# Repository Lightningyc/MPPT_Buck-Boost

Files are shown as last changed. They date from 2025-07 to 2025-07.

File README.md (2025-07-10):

&nbsp;&nbsp;

[English](./README.md)/中文

***
初赛演示视频：[2025年嵌入式设计大赛ST赛道-基于 STM32G4 平台的数控 MPPT 四开关 buckboost 变换器](https://www.bilibili.com/video/BV1HrGgzEE6s/)

# 作品实物图

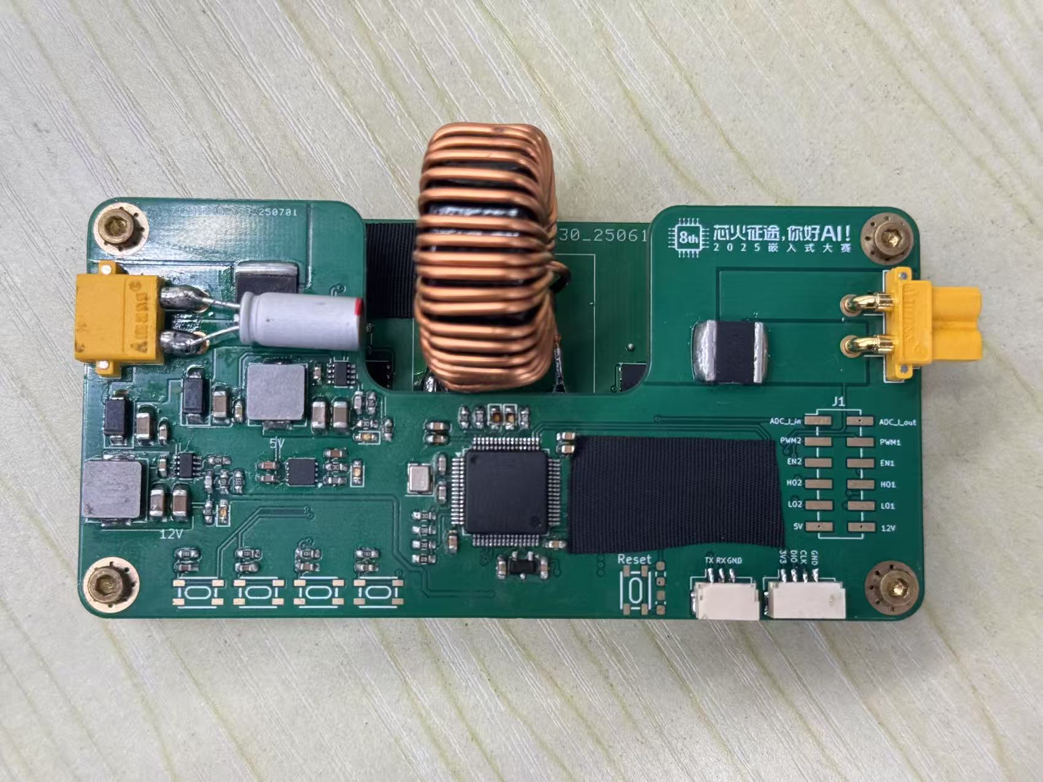
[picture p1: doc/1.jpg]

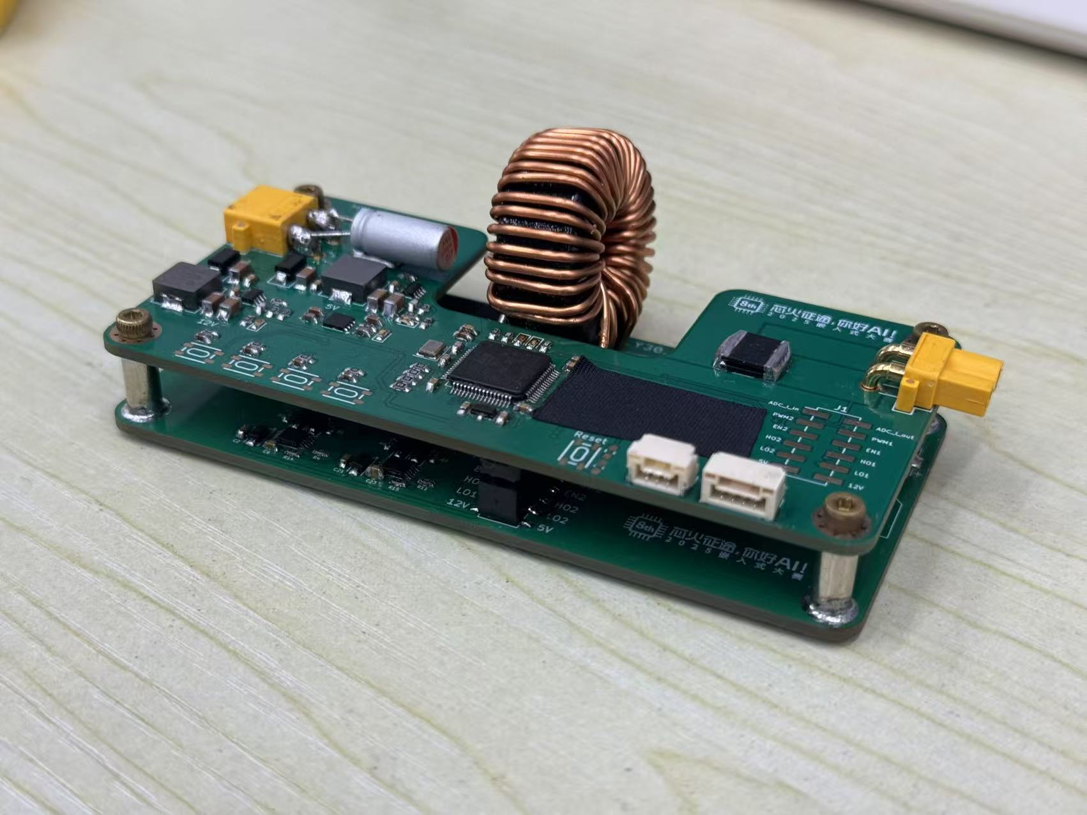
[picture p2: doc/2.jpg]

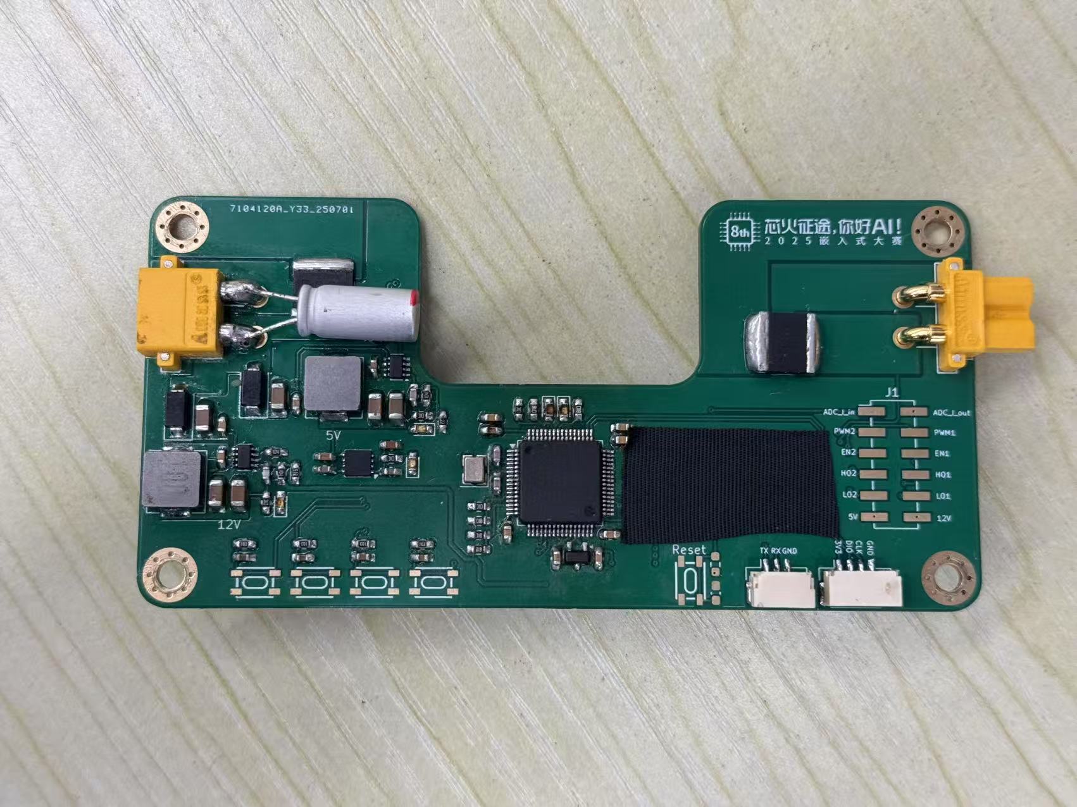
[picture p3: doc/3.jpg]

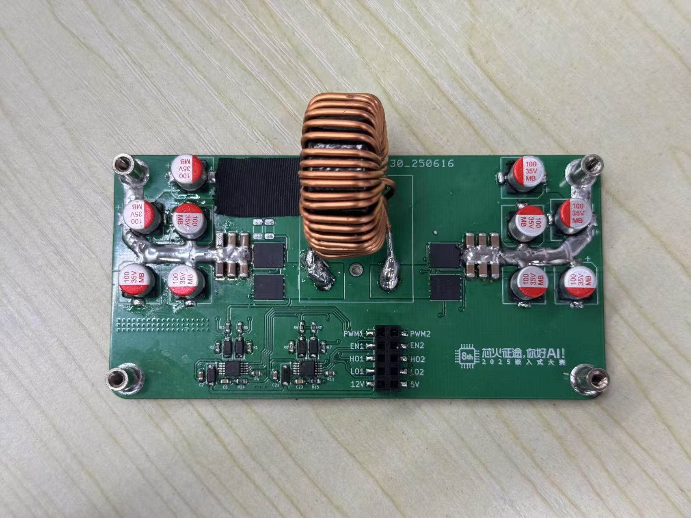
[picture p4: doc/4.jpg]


# 1. 作品简介

## 1.1 关键性能指标
**输出电压：**
最高输出电压：10.74V

最低输出电压：15.20V

**稳态平均功率：**

12.39W

**稳态功率波动：**

0.02%

**最大功率点跟踪效率：**

94.8%
## 1.2 主要创新点

1. 双模式 MPPT 算法：结合 CV 法快速定位与 P&O 法动态跟踪，提高追
踪精度，加强了抗光照突变干扰能力。

2. 太阳能控制器硬件部分采用双板结构：控制板含 MCU 最小系统、采
样电路及调试接口；功率板集成主变换电路、驱动及滤波电路。全部设计基
于 KiCad 完成，兼顾调试便利与高低压隔离需求。

3. 使用 PSIM 仿真：充分利用 PSIM 仿真软件进行算法验证和参数优化，
实现了仿真与硬件开发的双线并行，提高了工作效率，还能提前发现潜在问
题，为后续硬件调试奠定了坚实基础。

# 2. 系统介绍

下图所示的太阳能控制器系统包含以下核心模块：DC-DC 电能变换电路、电压电流采样电路、输入输出滤波电路以及辅助电源电路。系统工作原理如下：

能量输入与处理：光伏电池板转换的太阳能电能，经输入滤波电路预处理后，输入至 DC-DC 变换电路。

状态监测：STM32G74 微控制器周期性采集经采样电路获取的输入/输出电压电流数据。

核心控制：微控制器对采集数据进行线性拟合，并运行内部 MPPT 算法，计算出控制指令。

功率调节：控制指令转化为PWM信号输出至栅极驱动器，驱动 DC-DC 变换电路的功率开关器件，从而动态调整其工作状态（如占空比），实现对输入或输出电参数的精准控制。

通信交互： 控制器通过 UART 接口与上位机软件 Vofa+ 通信，支持参数远程设定及实时运行数据（电压/电流）反馈。

安全保障与供电：

输入端设有防电流倒灌电路，防止能量逆向流动。

辅助电源电路集成提供 12V、5V 和 3.3V 的板级电源，为控制器内部所有模块稳定供电。

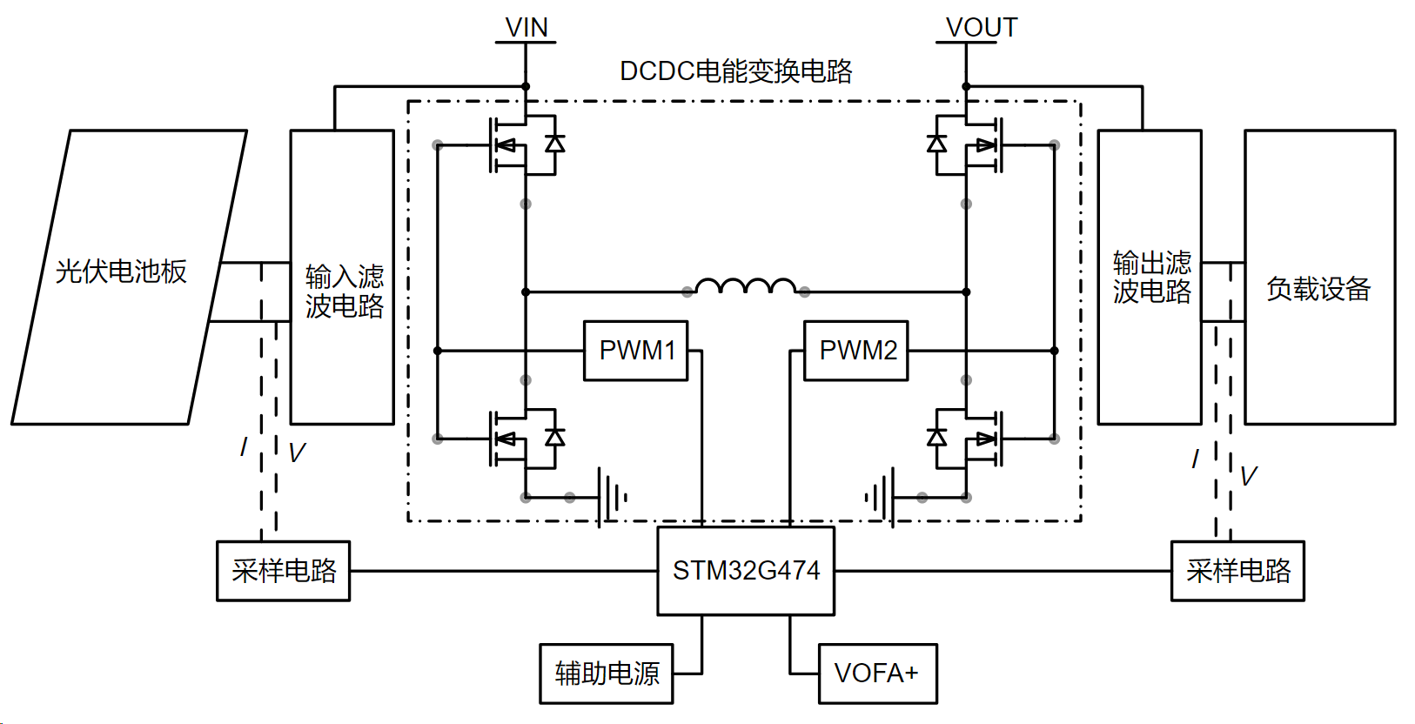
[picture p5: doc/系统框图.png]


考虑到调试方便性以及高低压域分割问题，本文中的太阳能电池板控制器的硬件系统主要由控制部分与功率部分两块 PCB 板组合而成，其如图 2 所示，控制部分主要包括主控 MCU 最小系统、辅助电源、采样电路、调试接口和指示灯；功率部分主要包括电能变换主电路，输入输出滤波电路和栅极驱动电路。本作品的硬件全流程设计均基于 Kicad 软件。

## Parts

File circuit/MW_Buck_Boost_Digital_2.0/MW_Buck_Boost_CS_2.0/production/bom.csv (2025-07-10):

Designator | Footprint | Quantity | Value | LCSC Part #
C1, C10, C11, C12, C13, C14, C15, C2, C22, C23, C24, C26, C3, C6, C7, C8, C9 | 0603 | 17 | 100n
C19, C20 | 1206 | 2 | 106 1206
C21, C25 | 0603 | 2 | 4.7u
C27, C28 | 0603 | 2 | 103
C29, C30 | 0603 | 2 | 101
C31, C32, C33, C34 | 1206 | 4 | 22uf 0603
C4, C5 | 0603 | 2 | 10p
D10, D8, D9 | 0603 | 3 | LED
D3 | 0603 | 1 | blue
D5 | 0603 | 1 | green
D6, D7 | D_SMA | 2 | B140-E3
H1, H2, H3, H4 | MountingHole_3.2mm_M3_Pad_Via | 4 | MountingHole_Pad
J2 | XT30PW-M | 1 | Conn_01x02
J3 | XT30PW-F | 1 | Conn_01x02
J4 | PinHeader_2x06_P2.54mm_Vertical_SMD | 1 | Conn_02x06_Odd_Even
J5 | JST_GH_SM04B-GHS-TB_1x04-1MP_P1.25mm_Horizontal | 1 | Conn_01x04
J6 | JST_GH_SM03B-GHS-TB_1x03-1MP_P1.25mm_Horizontal | 1 | Conn_01x03
J7 | PinSocket_1x04_P2.54mm_Vertical | 1 | Conn_01x04
J8 | PinHeader_2x05_P2.54mm_Vertical_SMD | 1 | Conn_02x05_Odd_Even
L1 | L_Abracon_ASPI-0630LR | 1 | 10uH
L2 | L_Abracon_ASPI-0630LR | 1 | 15uH
R10, R11, R3, R4, R8, R9 | 0603 | 6 | 10k
R12, R13 | 0603 | 2 | 6k
R14, R15, R18, R23, R24, R5, R7 | 0603 | 7 | 1k
R16, R17, R19, R21 | 0603 | 4 | 100k
R2 | Resistance | 1 | 8m
R20 | 0603 | 1 | 5.26k
R22 | 0603 | 1 | 11.4k
SW1, SW2, SW3, SW4, SW5 | SW-SMD_4P-L4.2-W3.3-P2.15-LS5.1 | 5 | SW_Push
U1 | SOT-23 | 1 | REF3030
U2 | LQFP-64_10x10mm_P0.5mm | 1 | STM32G474RCTx
U3 | SOT-23-5 | 1 | INA180A3
U6 | DFN-8-1EP_3x3mm_P0.65mm_EP1.55x2.4mm | 1 | AP7361C
U7, U8 | SOT-23-8 | 2 | SY8303
Y1 | Crystal_SMD_3225-4Pin_3.2x2.5mm | 1 | 25M

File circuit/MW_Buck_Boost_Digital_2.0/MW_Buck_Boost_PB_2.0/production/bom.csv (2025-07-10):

Designator | Footprint | Quantity | Value | LCSC Part #
C1, C13, C27, C28, C29, C3, C32, C33, C34, C4, C7, C8, C9 | 1206 | 13 | 22uf
C15, C16, C17, C18, C20, C35, C36, C38, C39, C40 | CP_Elec_8x10 | 10 | 100uf
C2, C21 | 0603 | 2 | 2.2uf
C23, C6 | 0603 | 2 | 10uf
D1, D2, D3, D6, D7, D8 | D_SOD-123 | 6 | B140-E3
H1, H2, H3, H4 | MountingHole_3.2mm_M3_Pad_Via | 4 | MountingHole_Pad
J2 | PinHeader_2x05_P2.54mm_Vertical_SMD | 1 | Conn_02x05_Odd_Even
L1 | PQ2918 | 1 | 47uH
Q1, Q2, Q3, Q4 | TDSON-8-1 | 4 | CSD18540Q5B
R1, R2, R7, R8 | 0603 | 4 | 4.7
R11, R3, R4, R5, R6, R9 | 0603 | 6 | 10k
R14, R15 | 0603 | 2 | 4.7R
R16 | 1206 | 1 | 4.7
U1, U2 | SOP50P490X110-10N | 2 | LM5106MM/NOPB

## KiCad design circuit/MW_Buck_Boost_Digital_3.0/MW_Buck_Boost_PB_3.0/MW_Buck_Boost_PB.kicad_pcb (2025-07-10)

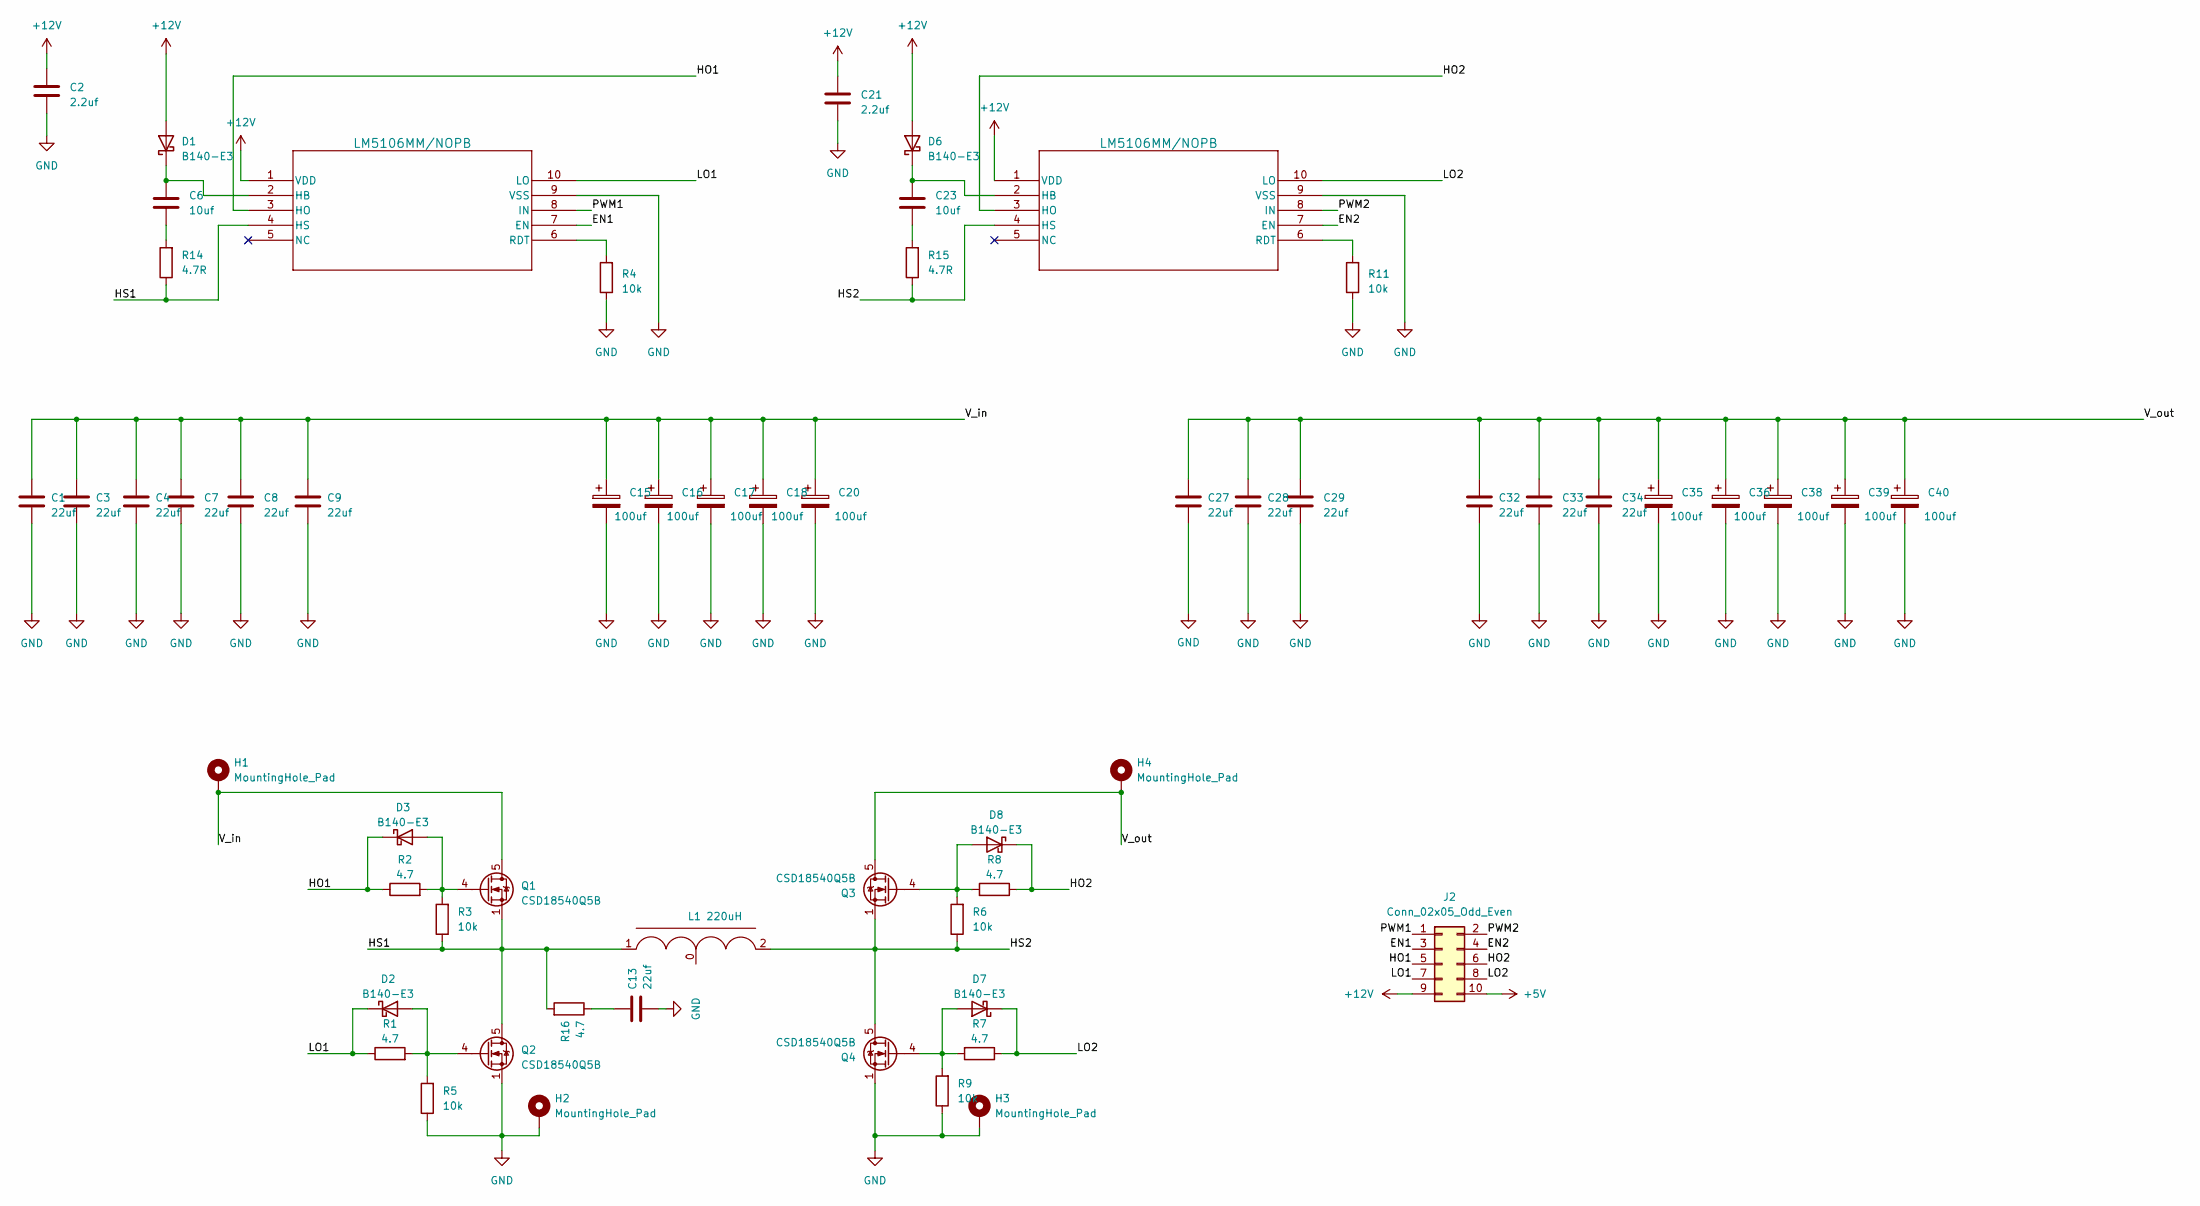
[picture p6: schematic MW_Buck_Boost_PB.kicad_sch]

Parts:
C1, C3, C4, C7, C8, C9, C13, C27, C28, C29, C32, C33, C34: 22uf; C_1206_3216Metric
C2, C21: 2.2uf; C_0603_1608Metric
C6, C23: 10uf; C_0603_1608Metric
C15, C16, C17, C18, C20, C35, C36, C38, C39, C40: 100uf; CP_Elec_8x10
D1, D2, D3, D6, D7, D8: B140-E3; D_SOD-123
H1, H2, H3, H4: MountingHole_Pad; MountingHole_3.2mm_M3_Pad_Via
J2: Conn_02x05_Odd_Even; PinHeader_2x05_P2.54mm_Vertical_SMD
L1: 220uH; L_Wurth_WE-HCFT-2012_LeadDiameter1.2mm
Q1, Q2, Q3, Q4: CSD18540Q5B; TDSON-8-1
R1, R2, R7, R8: 4.7; R_0603_1608Metric
R3, R4, R5, R6, R9, R11: 10k; R_0603_1608Metric
R14, R15: 4.7R; R_0603_1608Metric
R16: 4.7; R_1206_3216Metric
U1, U2: LM5106MM/NOPB; SOP50P490X110-10N

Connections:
+5V: J2.10
+12V: C2.1, C21.1, D1.2 (A), D6.2 (A), J2.9, U1.1 (VDD), U2.1 (VDD)
/EN1: J2.3, U1.7 (EN)
/EN2: J2.4, U2.7 (EN)
/HO1: D3.1 (K), J2.5, R2.1, U1.3 (HO)
/HO2: D8.1 (K), J2.6, R8.1, U2.3 (HO)
/HS1: L1.1, Q1.1 (S), Q1.2 (S), Q1.3 (S), Q2.5 (D), R3.1, R14.1, R16.2, U1.4 (HS)
/HS2: L1.2, Q3.1 (S), Q3.2 (S), Q3.3 (S), Q4.5 (D), R6.1, R15.1, U2.4 (HS)
/LO1: D2.1 (K), J2.7, R1.1, U1.10 (LO)
/LO2: D7.1 (K), J2.8, R7.1, U2.10 (LO)
/PWM1: J2.1, U1.8 (IN)
/PWM2: J2.2, U2.8 (IN)
/V_in: C1.1, C3.1, C4.1, C7.1, C8.1, C9.1, C15.1, C16.1, C17.1, C18.1, C20.1, H1.1, Q1.5 (D)
/V_out: C27.1, C28.1, C29.1, C32.1, C33.1, C34.1, C35.1, C36.1, C38.1, C39.1, C40.1, H4.1, Q3.5 (D)
GND: C1.2, C2.2, C3.2, C4.2, C7.2, C8.2, C9.2, C13.2, C15.2, C16.2, C17.2, C18.2, C20.2, C21.2, C27.2, C28.2, C29.2, C32.2, C33.2, C34.2, C35.2, C36.2, C38.2, C39.2, C40.2, H2.1, H3.1, Q2.1 (S), Q2.2 (S), Q2.3 (S), Q4.1 (S), Q4.2 (S), Q4.3 (S), R4.1, R5.1, R9.1, R11.1, U1.9 (VSS), U2.9 (VSS)
unnamed: C6.2, R14.2
unnamed: C13.1, R16.1
unnamed: C23.2, R15.2
unnamed: C6.1, D1.1 (K), U1.2 (HB)
unnamed: D2.2 (A), Q2.4 (G), R1.2, R5.2
unnamed: D3.2 (A), Q1.4 (G), R2.2, R3.2
unnamed: C23.1, D6.1 (K), U2.2 (HB)
unnamed: D7.2 (A), Q4.4 (G), R7.2, R9.2
unnamed: D8.2 (A), Q3.4 (G), R6.2, R8.2
unnamed: R4.2, U1.6 (RDT)
unnamed: R11.2, U2.6 (RDT)

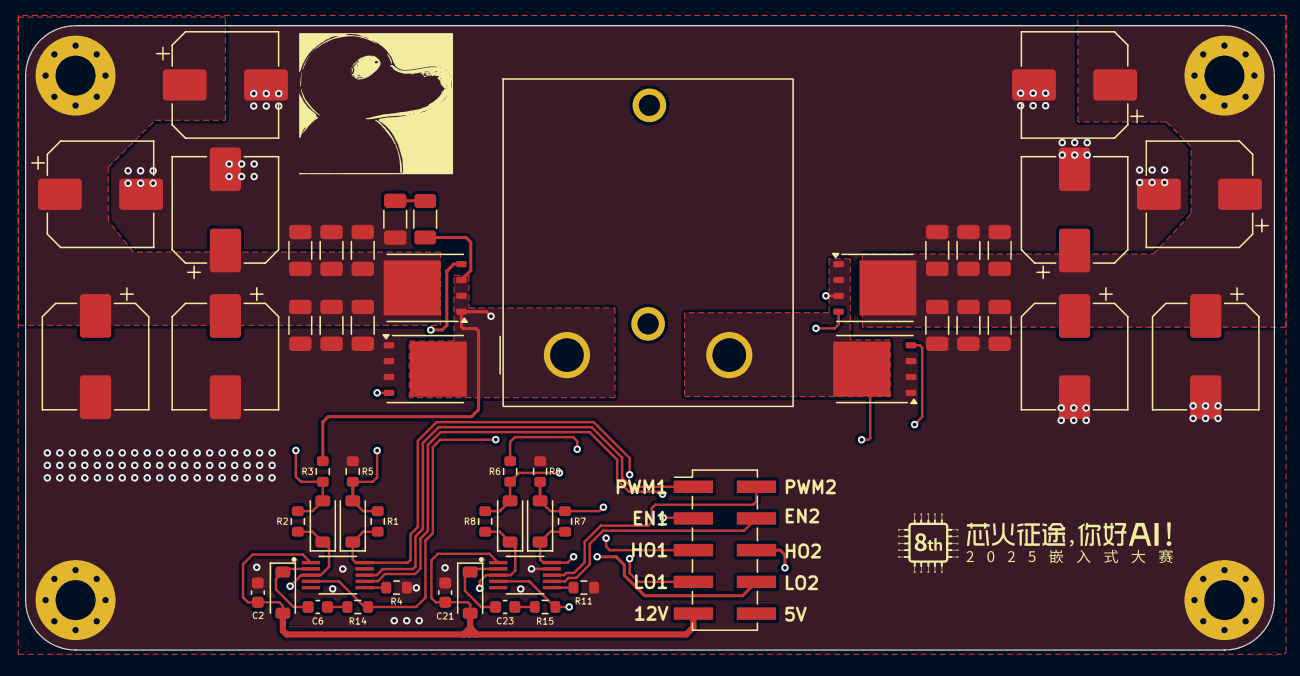
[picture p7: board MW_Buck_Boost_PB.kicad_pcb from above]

Board: 4 copper layers, 100.0 x 50.0 mm, 58 parts (0 on the bottom side), 25 nets.

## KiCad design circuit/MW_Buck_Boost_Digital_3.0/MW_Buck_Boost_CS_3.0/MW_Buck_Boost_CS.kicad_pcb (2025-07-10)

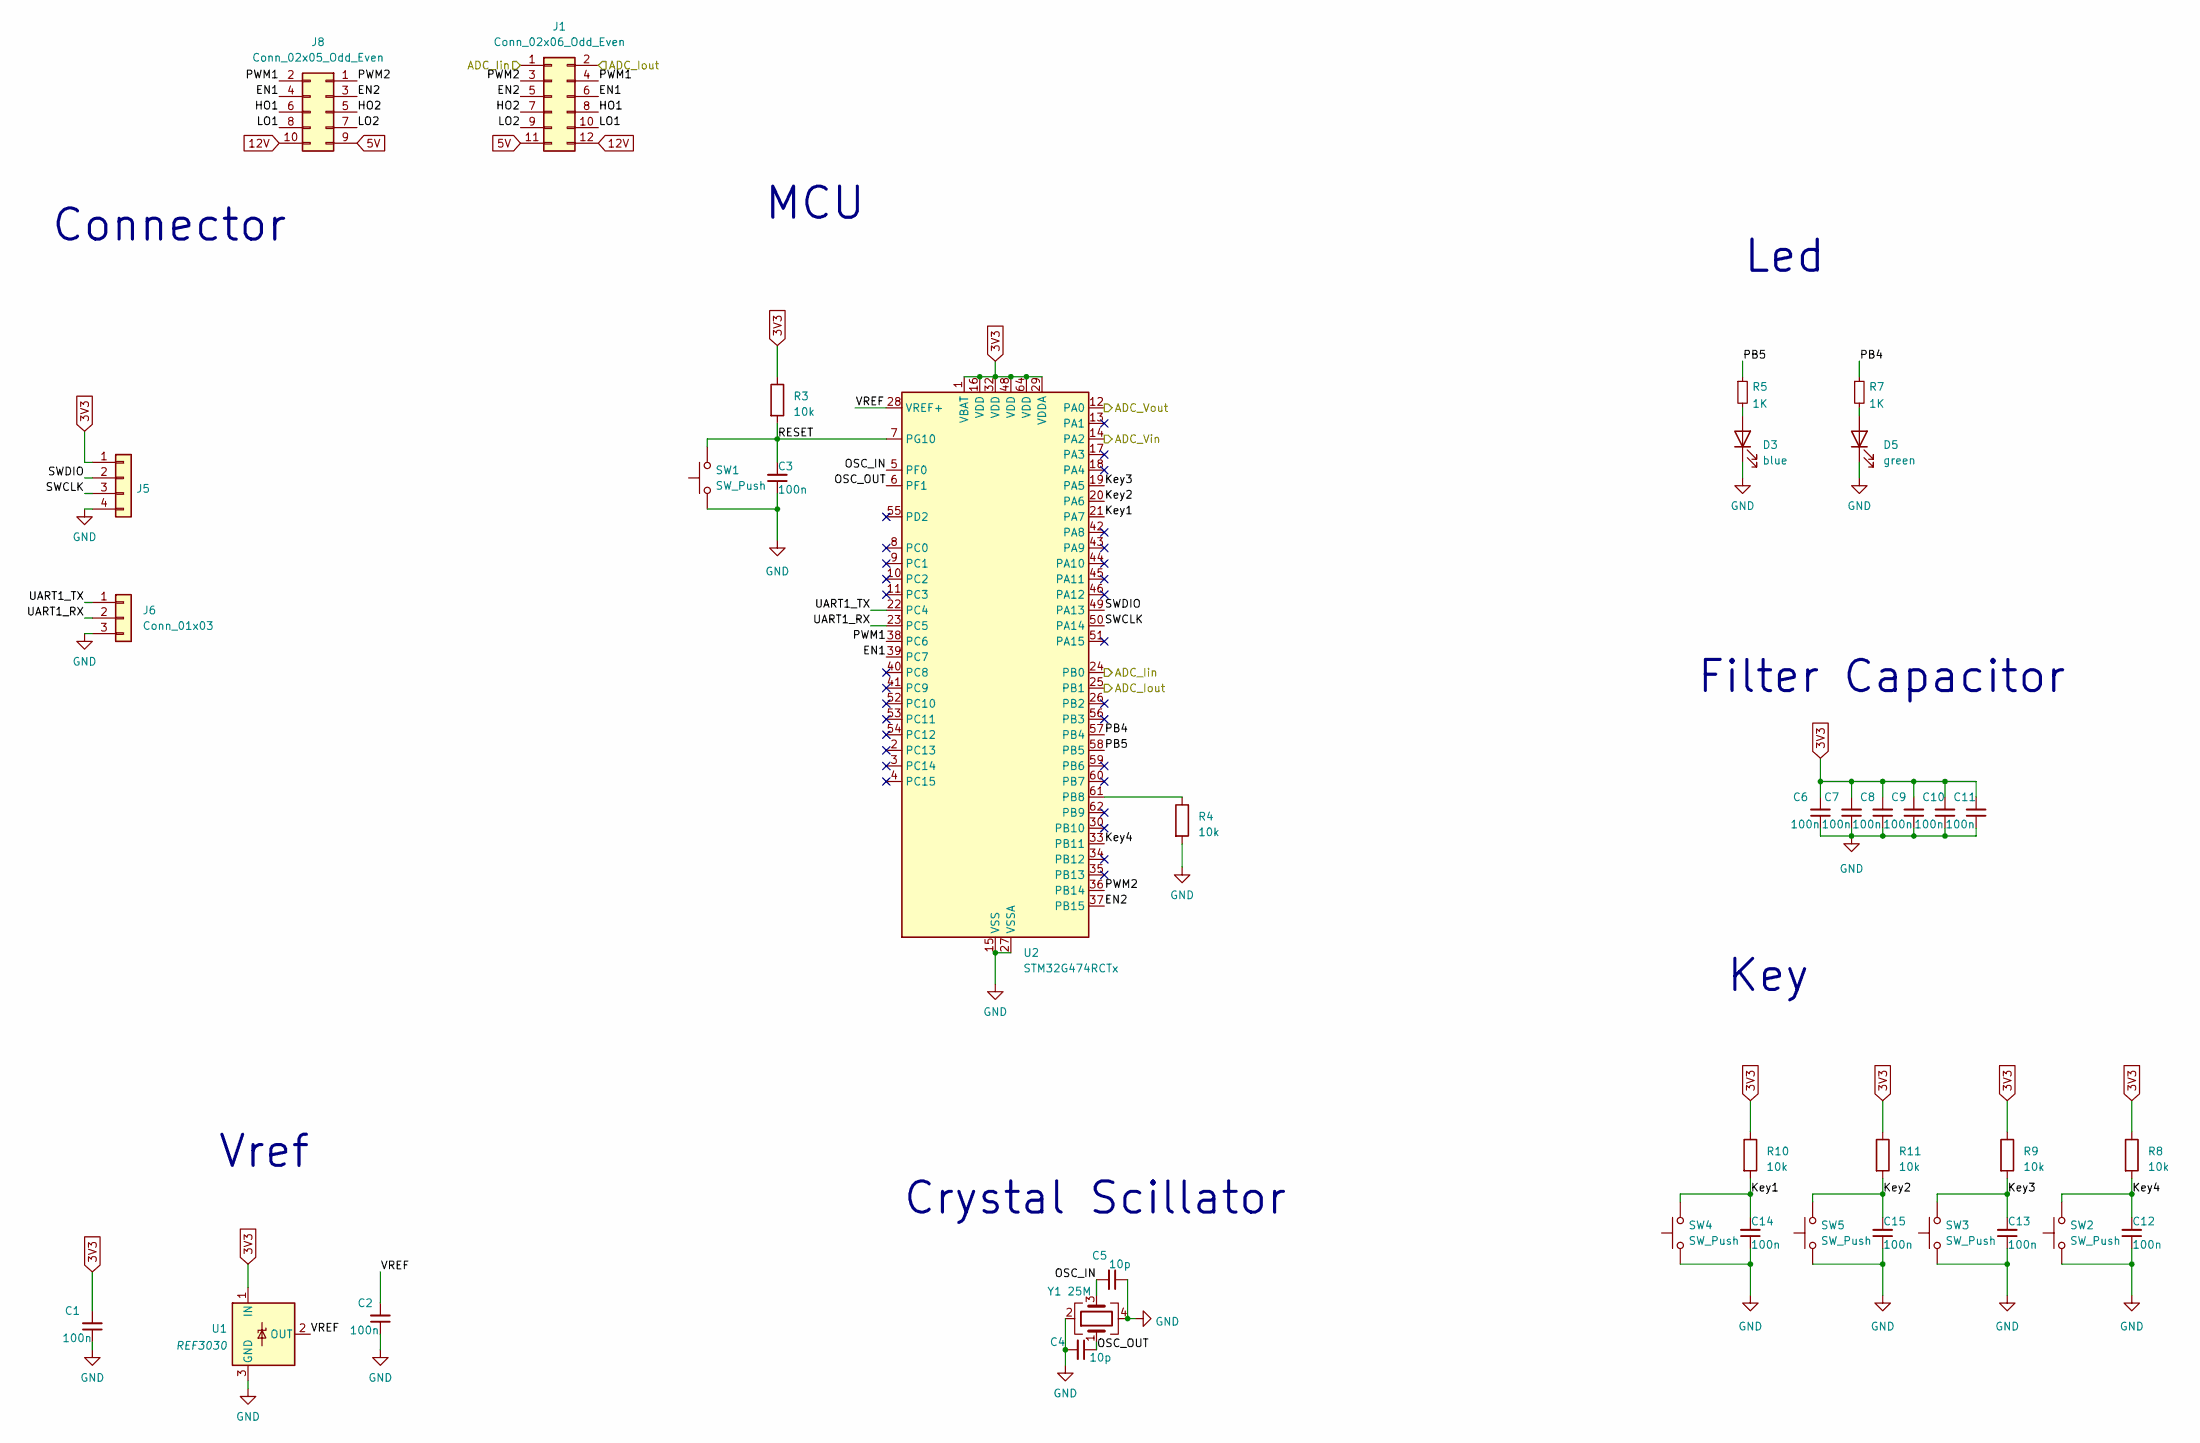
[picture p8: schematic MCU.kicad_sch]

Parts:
C1, C2, C3, C6, C7, C8, C9, C10, C11, C12, C13, C14, C15: 100n; C_0603_1608Metric_Pad1.08x0.95mm_HandSolder
C4, C5: 10p; C_0603_1608Metric_Pad1.08x0.95mm_HandSolder
D3: blue; LED_0603_1608Metric_Pad1.05x0.95mm_HandSolder
D5: green; LED_0603_1608Metric_Pad1.05x0.95mm_HandSolder
J1: Conn_02x06_Odd_Even; PinHeader_2x06_P2.54mm_Vertical_SMD
J5: Conn_01x04; JST_GH_SM04B-GHS-TB_1x04-1MP_P1.25mm_Horizontal
J6: Conn_01x03; JST_GH_SM03B-GHS-TB_1x03-1MP_P1.25mm_Horizontal
J8: Conn_02x05_Odd_Even; PinHeader_2x05_P2.54mm_Vertical_SMD
R3, R4, R8, R9, R10, R11: 10k; R_0603_1608Metric_Pad0.98x0.95mm_HandSolder
R5, R7: 1K; R_0603_1608Metric_Pad0.98x0.95mm_HandSolder
SW1, SW2, SW3, SW4, SW5: SW_Push; SW-SMD_4P-L4.2-W3.3-P2.15-LS5.1
U1: REF3030; SOT-23
U2: STM32G474RCTx; LQFP-64_10x10mm_P0.5mm
Y1: 25M; Crystal_SMD_3225-4Pin_3.2x2.5mm

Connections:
3V3: C1.2, C6.2, C7.2, C8.2, C9.2, C10.2, C11.2, J5.1, R3.1, R8.1, R9.1, R10.1, R11.1, U1.1 (IN), U2.1 (VBAT), U2.16 (VDD), U2.29 (VDDA), U2.32 (VDD), U2.48 (VDD), U2.64 (VDD); also elsewhere on the board
5V: J1.11, J8.9; also elsewhere on the board
12V: J1.12, J8.10; also elsewhere on the board
/MCU/ADC_Iin: J1.1, U2.24 (PB0); also elsewhere on the board
/MCU/ADC_Iout: J1.2, U2.25 (PB1); also elsewhere on the board
/MCU/ADC_Vin: U2.14 (PA2); also elsewhere on the board
/MCU/ADC_Vout: U2.12 (PA0); also elsewhere on the board
/MCU/EN1: J1.6, J8.4, U2.39 (PC7)
/MCU/EN2: J1.5, J8.3, U2.37 (PB15)
/MCU/HO1: J1.8, J8.6
/MCU/HO2: J1.7, J8.5
/MCU/Key1: C14.2, R10.2, SW4.2, U2.21 (PA7)
/MCU/Key2: C15.2, R11.2, SW5.2, U2.20 (PA6)
/MCU/Key3: C13.2, R9.2, SW3.2, U2.19 (PA5)
/MCU/Key4: C12.2, R8.2, SW2.2, U2.33 (PB11)
/MCU/LO1: J1.10, J8.8
/MCU/LO2: J1.9, J8.7
/MCU/OSC_IN: C5.2, U2.5 (PF0), Y1.3
/MCU/OSC_OUT: C4.1, U2.6 (PF1), Y1.1
/MCU/PB4: R7.1, U2.57 (PB4)
/MCU/PB5: R5.1, U2.58 (PB5)
/MCU/PWM1: J1.4, J8.2, U2.38 (PC6)
/MCU/PWM2: J1.3, J8.1, U2.36 (PB14)
/MCU/RESET: C3.2, R3.2, SW1.2, U2.7 (PG10)
/MCU/SWCLK: J5.3, U2.50 (PA14)
/MCU/SWDIO: J5.2, U2.49 (PA13)
/MCU/UART1_RX: J6.2, U2.23 (PC5)
/MCU/UART1_TX: J6.1, U2.22 (PC4)
/MCU/VREF: C2.2, U1.2 (OUT), U2.28 (VREF+)
GND: C1.1, C2.1, C3.1, C4.2, C5.1, C6.1, C7.1, C8.1, C9.1, C10.1, C11.1, C12.1, C13.1, C14.1, C15.1, D3.1 (K), D5.1 (K), J5.4, J6.3, R4.2, SW1.1, SW2.1, SW3.1, SW4.1, SW5.1, U1.3 (GND), U2.15 (VSS), U2.27 (VSSA), U2.31 (VSS), U2.47 (VSS), U2.63 (VSS), Y1.2, Y1.4; also elsewhere on the board
unnamed: D3.2 (A), R5.2
unnamed: D5.2 (A), R7.2
unnamed: R4.1, U2.61 (PB8)

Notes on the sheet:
Connector
Led
Vref
Crystal Scillator
MCU
Filter Capacitor
Key

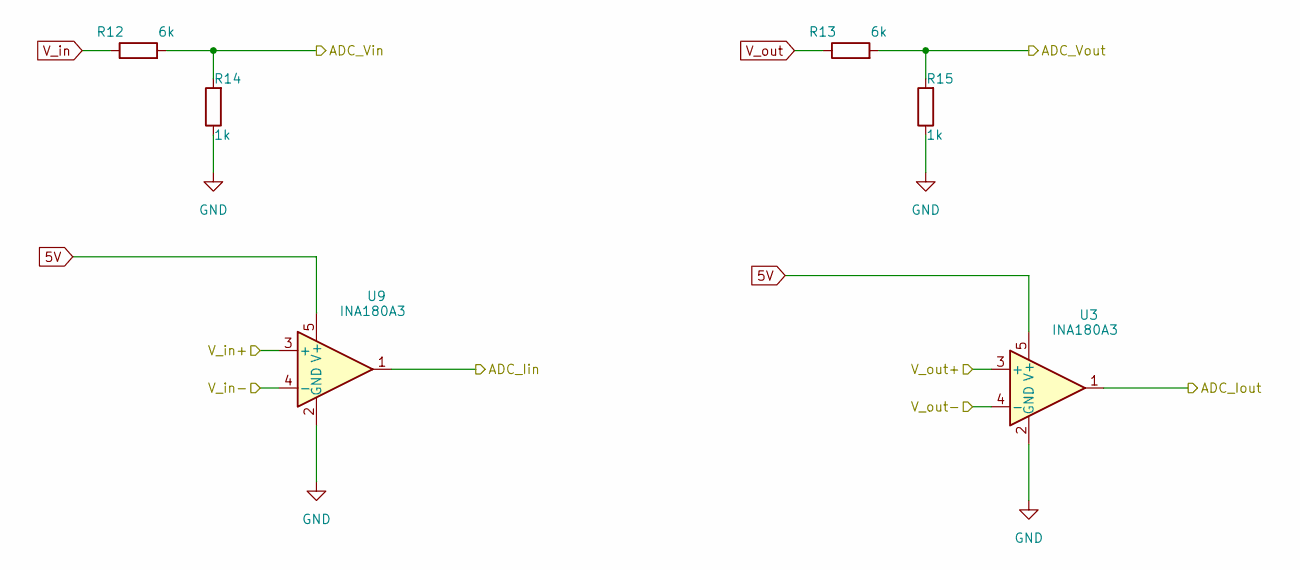
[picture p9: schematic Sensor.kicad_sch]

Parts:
R12, R13: 6k; R_0603_1608Metric_Pad0.98x0.95mm_HandSolder
R14, R15: 1k; R_0603_1608Metric_Pad0.98x0.95mm_HandSolder
U3, U9: INA180A3; SOT-23-5

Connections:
5V: U3.5 (V+), U9.5 (V+); also elsewhere on the board
/MCU/ADC_Iin: U9.1; also elsewhere on the board
/MCU/ADC_Iout: U3.1; also elsewhere on the board
/MCU/ADC_Vin: R12.2, R14.2; also elsewhere on the board
/MCU/ADC_Vout: R13.2, R15.2; also elsewhere on the board
/MainCircuit/V_in-: U9.4 (-); also elsewhere on the board
/MainCircuit/V_out+: U3.3 (+); also elsewhere on the board
GND: R14.1, R15.1, U3.2 (GND), U9.2 (GND); also elsewhere on the board
V_in: R12.1, U9.3 (+); also elsewhere on the board
V_out: R13.1, U3.4 (-); also elsewhere on the board

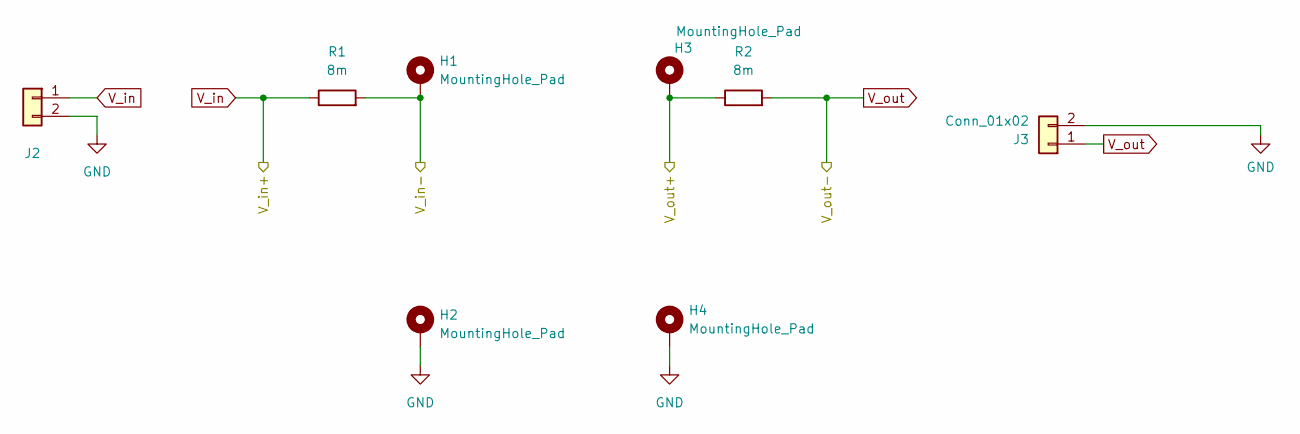
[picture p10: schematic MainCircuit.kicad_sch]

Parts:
H1, H2, H3, H4: MountingHole_Pad; MountingHole_3.2mm_M3_Pad_Via
J2: Conn_01x02; XT30PW-M
J3: Conn_01x02; XT30PW-F
R1, R2: 8m; Resistance

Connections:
/MainCircuit/V_in-: H1.1, R1.2; also elsewhere on the board
/MainCircuit/V_out+: H3.1, R2.1; also elsewhere on the board
GND: H2.1, H4.1, J2.2, J3.2; also elsewhere on the board
V_in: J2.1, R1.1; also elsewhere on the board
V_out: J3.1, R2.2; also elsewhere on the board

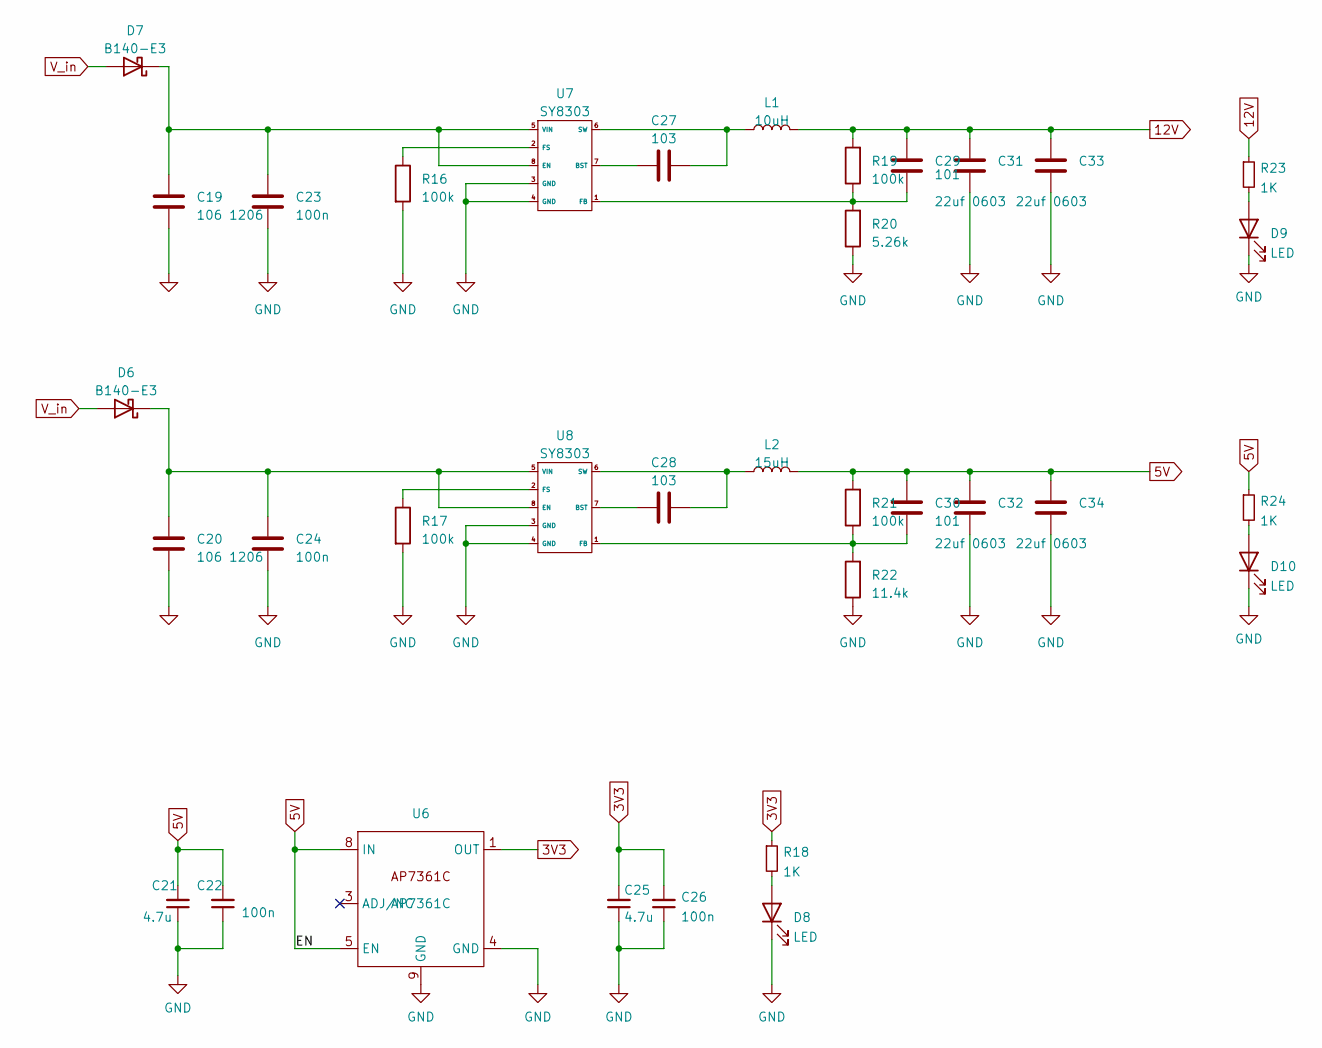
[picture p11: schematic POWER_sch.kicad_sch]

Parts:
C19, C20: 106 1206; C_1206_3216Metric_Pad1.33x1.80mm_HandSolder
C21, C25: 4.7u; C_0603_1608Metric_Pad1.08x0.95mm_HandSolder
C22, C23, C24, C26: 100n; C_0603_1608Metric_Pad1.08x0.95mm_HandSolder
C27, C28: 103; C_0603_1608Metric_Pad1.08x0.95mm_HandSolder
C29, C30: 101; C_0603_1608Metric_Pad1.08x0.95mm_HandSolder
C31, C32, C33, C34: 22uf 0603; C_1206_3216Metric_Pad1.33x1.80mm_HandSolder
D6, D7: B140-E3; D_SMA
D8, D9, D10: LED; LED_0603_1608Metric_Pad1.05x0.95mm_HandSolder
L1: 10uH; L_Abracon_ASPI-0630LR
L2: 15uH; L_Abracon_ASPI-0630LR
R16, R17, R19, R21: 100k; R_0603_1608Metric_Pad0.98x0.95mm_HandSolder
R18, R23, R24: 1K; R_0603_1608Metric_Pad0.98x0.95mm_HandSolder
R20: 5.26k; R_0603_1608Metric_Pad0.98x0.95mm_HandSolder
R22: 11.4k; R_0603_1608Metric_Pad0.98x0.95mm_HandSolder
U6: AP7361C; DFN-8-1EP_3x3mm_P0.65mm_EP1.55x2.4mm
U7, U8: SY8303; SOT-23-8

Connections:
3V3: C25.2, C26.2, R18.1, U6.1 (OUT); also elsewhere on the board
5V: C21.2, C22.2, C30.2, C32.2, C34.2, L2.2, R21.2, R24.1, U6.5 (EN), U6.8 (IN); also elsewhere on the board
12V: C29.2, C31.2, C33.2, L1.2, R19.2, R23.1; also elsewhere on the board
GND: C19.1, C20.1, C21.1, C22.1, C23.1, C24.1, C25.1, C26.1, C31.1, C32.1, C33.1, C34.1, D8.1 (K), D9.1 (K), D10.1 (K), R16.2, R17.2, R20.1, R22.1, U6.4 (GND), U6.9 (GND), U7.3 (GND), U7.4 (GND), U8.3 (GND), U8.4 (GND); also elsewhere on the board
unnamed: C20.2, C24.2, D6.1 (K), U8.5 (VIN), U8.8 (EN)
unnamed: C19.2, C23.2, D7.1 (K), U7.5 (VIN), U7.8 (EN)
unnamed: D8.2 (A), R18.2
unnamed: D9.2 (A), R23.2
unnamed: D10.2 (A), R24.2
unnamed: C27.1, U7.7 (BST)
unnamed: C29.1, R19.1, R20.2, U7.1 (FB)
unnamed: R16.1, U7.2 (FS)
unnamed: C27.2, L1.1, U7.6 (SW)
unnamed: C28.1, U8.7 (BST)
unnamed: C30.1, R21.1, R22.2, U8.1 (FB)
unnamed: R17.1, U8.2 (FS)
unnamed: C28.2, L2.1, U8.6 (SW)
V_in: D6.2 (A), D7.2 (A); also elsewhere on the board

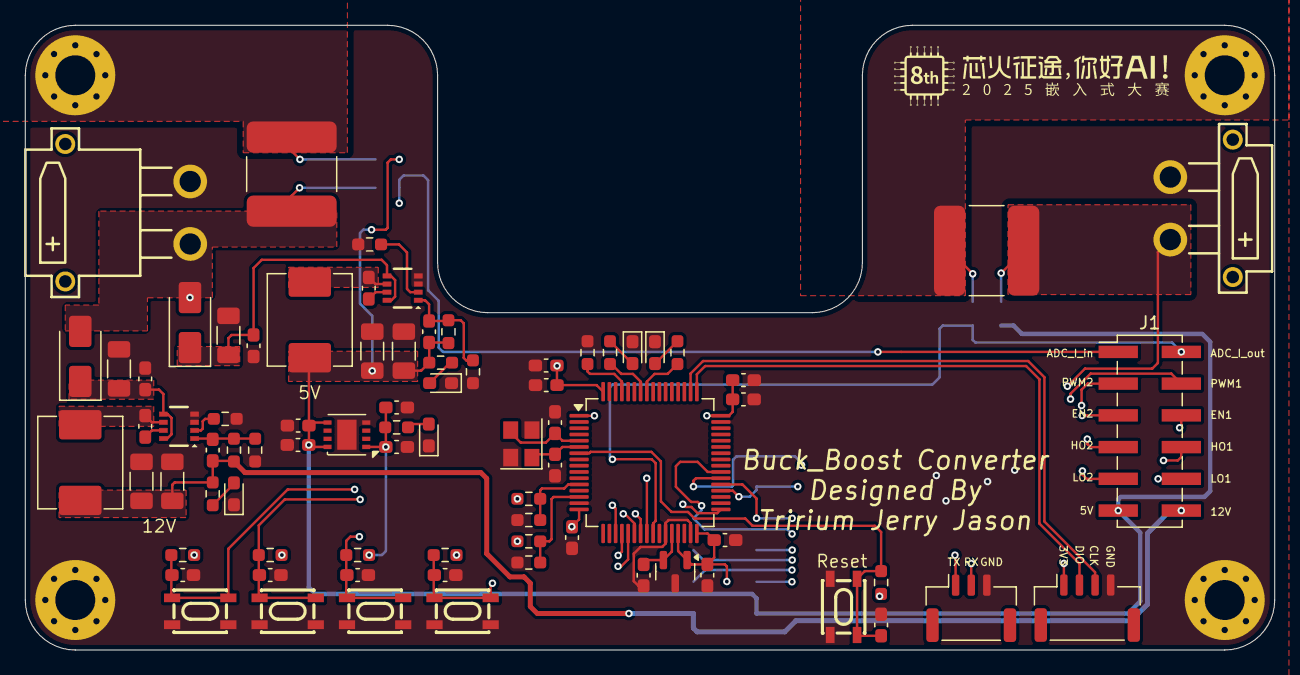
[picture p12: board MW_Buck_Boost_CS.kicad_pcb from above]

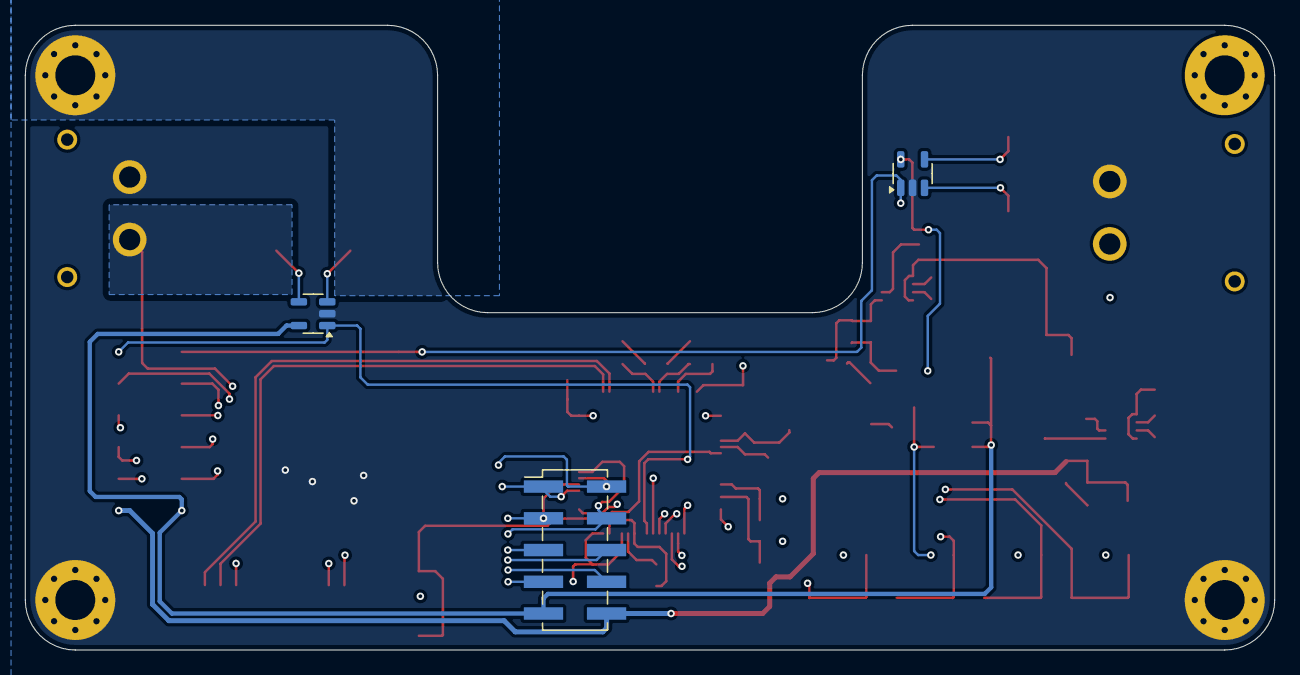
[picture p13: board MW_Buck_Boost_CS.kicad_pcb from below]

Board: 4 copper layers, 100.0 x 50.0 mm, 86 parts (3 on the bottom side), 50 nets.

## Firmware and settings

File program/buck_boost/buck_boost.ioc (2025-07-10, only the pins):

Mcu.UserName=STM32G474RCTx
PA0.Signal=ADC1_IN1
PA13.Signal=SYS_JTMS-SWDIO
PA14.Signal=SYS_JTCK-SWCLK
PA2.Signal=ADC1_IN3
PB0.Signal=ADC1_IN15
PB1.Signal=ADC1_IN12
PB14.Signal=HRTIM1_CHD1
PB15.Signal=GPIO_Output
PB4.Signal=GPIO_Output
PB5.Signal=GPIO_Output
PB6.Signal=GPIO_Output
PC10.Signal=GPIO_Output
PC11.Signal=GPIO_Output
PC4.Signal=USART1_TX
PC5.Signal=USART1_RX
PC6.Signal=HRTIM1_CHF1
PC7.Signal=GPIO_Output
PF0-OSC_IN.Signal=RCC_OSC_IN
PF1-OSC_OUT.Signal=RCC_OSC_OUT

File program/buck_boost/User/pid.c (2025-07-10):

//
// Created by »Æ on 2024/6/7.
//

#include "pid.h"


volatile uint16_t AD_Value[4] = {0};
dcdc_control buck_control = {0, 0, 0, 0, 0, 0, 0, 0, 0, 0, buck};
dcdc_control buck_boost_control = {0, 0, 0, 0, 0, 0, 0, 0, 0, 0, buck_boost};
control_mode running_mode;
volatile uint8_t protect_flag = 0;
uint8_t begin_flag = 0;

void dcdc_control_init(dcdc_control *control, float P, float I, int error_integral_limit, uint16_t feedforward,
                       int target) {
    control->P = P;
    control->I = I;
    control->error_integral_limit = error_integral_limit;
    control->feedforward = feedforward;
    control->control_target = target;
}


void PI_updata(dcdc_control *control) {
    control->error = control->control_target - VOUT;
    control->error_integral = (control->error_integral + control->error);
//    if (control->error_integral > control->error_integral_limit) {
//        control->error_integral = control->error_integral_limit;
//    }
    control->PI_output = (int) ((control->P * (float) control->error) +
                                control->I * (float) control->error_integral);
}


inline void updata_pwm(dcdc_control *control) {
    if (control->mode == buck) {
        control->feedforward = (uint16_t) (54400 * 20.0f / (VIN * VIN_ADC_coefficient));
        if (begin_flag == 1) {

            PI_updata(control);
            control->control_output = (uint16_t) (control->feedforward + (control->PI_output >> 2));
            if (control->control_output > pwm_H_limit) {
                control->control_output = pwm_H_limit;
            } else if (control->control_output < pwm_L_limit) {
                control->control_output = pwm_L_limit;
            }
            hhrtim1.Instance->sTimerxRegs[3].CMP1xR = 1000;
            hhrtim1.Instance->sTimerxRegs[5].CMP1xR = control->control_output;
        } else {
            hhrtim1.Instance->sTimerxRegs[3].CMP1xR = 1000;
            hhrtim1.Instance->sTimerxRegs[5].CMP1xR = control->feedforward;
        }

    } else if (control->mode == buck_boost) {
        control->feedforward = (uint16_t) ((20.0f /
                                            (VIN * VIN_ADC_coefficient + 20.0f)) *
                                           54400);
        if (begin_flag == 1) {
            PI_updata(control);
            control->control_output = (uint16_t) (control->feedforward + (control->PI_output >> 2));
            if (control->control_output > 32000) {
                control->control_output = 32000;
            } else if (control->control_output < pwm_L_limit) {
                control->control_output = pwm_L_limit;
            }
            hhrtim1.Instance->sTimerxRegs[3].CMP1xR = control->control_output;
            hhrtim1.Instance->sTimerxRegs[5].CMP1xR = control->control_output;
        } else {
            hhrtim1.Instance->sTimerxRegs[3].CMP1xR = control->feedforward;
            hhrtim1.Instance->sTimerxRegs[5].CMP1xR = control->feedforward;
        }

    }
}

void buck_on(dcdc_control *control) {
    control->mode = buck;
    static HRTIM_TimeBaseCfgTypeDef buck_config;
    buck_config.Period = 54400;
    buck_config.RepetitionCounter = 0;
    buck_config.PrescalerRatio = HRTIM_PRESCALERRATIO_DIV1;
    buck_config.Mode = HRTIM_MODE_CONTINUOUS;
    HAL_HRTIM_TimeBaseConfig(&hhrtim1, HRTIM_TIMERINDEX_TIMER_D, &buck_config);
}

void buck_boost_on(dcdc_control *control) {
    control->mode = buck_boost;
    static HRTIM_TimeBaseCfgTypeDef buck_config;
    buck_config.Period = 54400;
    buck_config.RepetitionCounter = 0;
    buck_config.PrescalerRatio = HRTIM_PRESCALERRATIO_MUL16;
    buck_config.Mode = HRTIM_MODE_CONTINUOUS;
    HAL_HRTIM_TimeBaseConfig(&hhrtim1, HRTIM_TIMERINDEX_TIMER_D, &buck_config);

}

inline void control_run(dcdc_control *buck_controler, dcdc_control *buck_boost_controler) {
    if (running_mode == buck) {
        updata_pwm(buck_controler);
        HAL_GPIO_WritePin(GPIOB, GPIO_PIN_5, GPIO_PIN_RESET);
        HAL_GPIO_WritePin(GPIOB, GPIO_PIN_4, GPIO_PIN_SET);
    } else if (running_mode == buck_boost) {
        updata_pwm(buck_boost_controler);
        HAL_GPIO_WritePin(GPIOB, GPIO_PIN_5, GPIO_PIN_SET);
        HAL_GPIO_WritePin(GPIOB, GPIO_PIN_4, GPIO_PIN_RESET);
    }
}

void Hysteresis_comparator(dcdc_control *buck_controler, dcdc_control *buck_boost_controler) {

    if (buck_controler->mode == buck && VIN < 2800 - Hysteresis_Band) {
        buck_boost_on(buck_boost_controler);
        running_mode = buck_boost;
    } else if (buck_boost_controler->mode == buck_boost && VIN > 2800 + Hysteresis_Band) {
        buck_on(buck_controler);
        running_mode = buck;
    }
}

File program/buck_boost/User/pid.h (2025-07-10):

//
// Created by »Æ on 2024/6/7.
//

#ifndef PROJECT_PID_H
#define PROJECT_PID_H

#include "main.h"
#include "hrtim.h"

#define pwm_H_limit 50000
#define pwm_L_limit 5440
#define Hysteresis_Band 25
#define VOUT AD_Value[0]
#define Iout AD_Value[2]
#define Iin AD_Value[3]
#define VIN AD_Value[1]
#define VIN_ADC_coefficient (33.0f/4095)
#define VOUT_ADC_coefficient (21.0f/4095.0f)
#define Iout_ADC_coefficient (3.0f/3276)
#define Iin_ADC_coefficient (3.0f/3276)
typedef enum {
    buck,
    buck_boost
} control_mode;

typedef struct {
    float P;
    float I;
    int error;
    int last_err;
    int error_integral;
    int error_integral_limit;
    int PI_output;

    int control_target;

    uint16_t feedforward;
    uint16_t control_output;
    control_mode mode;
} dcdc_control;


extern volatile uint16_t AD_Value[4];
extern dcdc_control buck_control;
extern dcdc_control buck_boost_control;
extern volatile uint8_t protect_flag;

extern void Hysteresis_comparator(dcdc_control *buck_controler, dcdc_control *buck_boost_controler);

extern void dcdc_control_init(dcdc_control *control, float P, float I, int error_integral_limit, uint16_t feedforward,
                              int target);

extern void control_run(dcdc_control *buck_controler, dcdc_control *buck_boost_controler);

extern uint8_t begin_flag;


#endif //PROJECT_PID_H
